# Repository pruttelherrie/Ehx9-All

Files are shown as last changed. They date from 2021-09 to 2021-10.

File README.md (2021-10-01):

## WARNING! 
Do not use the EEPROM store code from before 2021-10-01! It will eat up your flash writes like candy because of the braindead EEPROM.write lib in the stm32duino core. Fixed in callbacks.h and main.cpp, dd 2021-10-01

## Ehx9-All: combining and programming EHX '9' pedals

Electro Harmonix' 9 series of pedals is a range of polyphonic synthesis pedals for guitar. The
effects and sounds that can be obtained are superb, however they have a few shortcomings: 
first of all they are not programmable (i.e. there's only one setting, no way to store 
favourites and recall them quickly) and if you have more than one, they tend to take
up quite a lot of space on a pedalboard, especially if one uses them only sparingly
during a set.

The modifications documented in this repository try to eliminate these shortcomings.

## Programmability

To store and recall settings, the pots and switch are removed. GPIOs from the
microcontroller are connected to the main board to replace the functionality of
the pots and the switch. Since we use a PWM signal for the pots, it is low-pass
filtered by a simple first-order RC network.

Encoders take the place of the pots and the switch, a TFT is added for visual 
feedback of the settings.

## Space saving

All pedals of this serie share the same PCB. The difference is in the firmware of the
DSP. This firmware is stored in an EEPROM. By multiplexing multiple EEPROMS on one
board and resetting the DSP after switching the multiplexer, one can switch between
pedals of the series within one enclosure.

## Implementing the mods

Modding a pedal is not for the faint of heart. It is pretty easy to destroy the pedal
in the process. Also, a number of tools are needed:

* A way to program an Attiny2313. I use a Tuxgraphics AVR programmer, but there's a large number of other options.
* A way to program the STM32 blackpill. I use an ST-Link clone.
* There's SMD (de) soldering involved
* The enclosure is modified

## BOM

The BOMs for the PCBs can be found in their folders:
[controller](./controller-pcb/ibom.html)
[multiplexer](./multiplexer-pcb/ibom.html)

## Firmware

The multiplexer firmware was made with the Arduino IDE.

The controller firmware was made with VSCode + PlatformIO.

## Walkthrough of a mod

TBD: text and images.

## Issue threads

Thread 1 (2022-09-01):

EEPROM

leetut, 2022-09-01:
Hi, how did you copy and write the eeprom?

pruttelherrie, 2022-09-13:
Hi, I did it with flashrom, but I believe you already managed to copy it, seeing the thread on diystompboxes :)

Robertzep, 2023-05-18:
Hi, I would like a little more info on how to copy the eeproms. I'd like to do it from the JTAG connector on the EHX x9 pedal. Also, on the Mel9 there is a larger eeprom (MX25L12833F). How do you deal with it or is the program size the same as the other pedals that use the MX25L6445E? I would like to correspond with you on this project. I've tried to join diystompboxes for awhile and never got an activation. I see that everything is here firmware and PCB's. I have been putting together your data from diystompboxes, imgur.com, and your Youtube channel to make this build a little clearer. Anyway, I have more questions too. You can reply to me on email if you like robertzep[at]neo.rr.com

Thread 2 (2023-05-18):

multiplexer BOM

Robertzep, 2023-05-18:
The BOM for the multiplexer PCB is missing.

pruttelherrie, 2023-05-19:
Added!

Robertzep, 2023-05-19:
Thanks!

Closed 2023-05-19.

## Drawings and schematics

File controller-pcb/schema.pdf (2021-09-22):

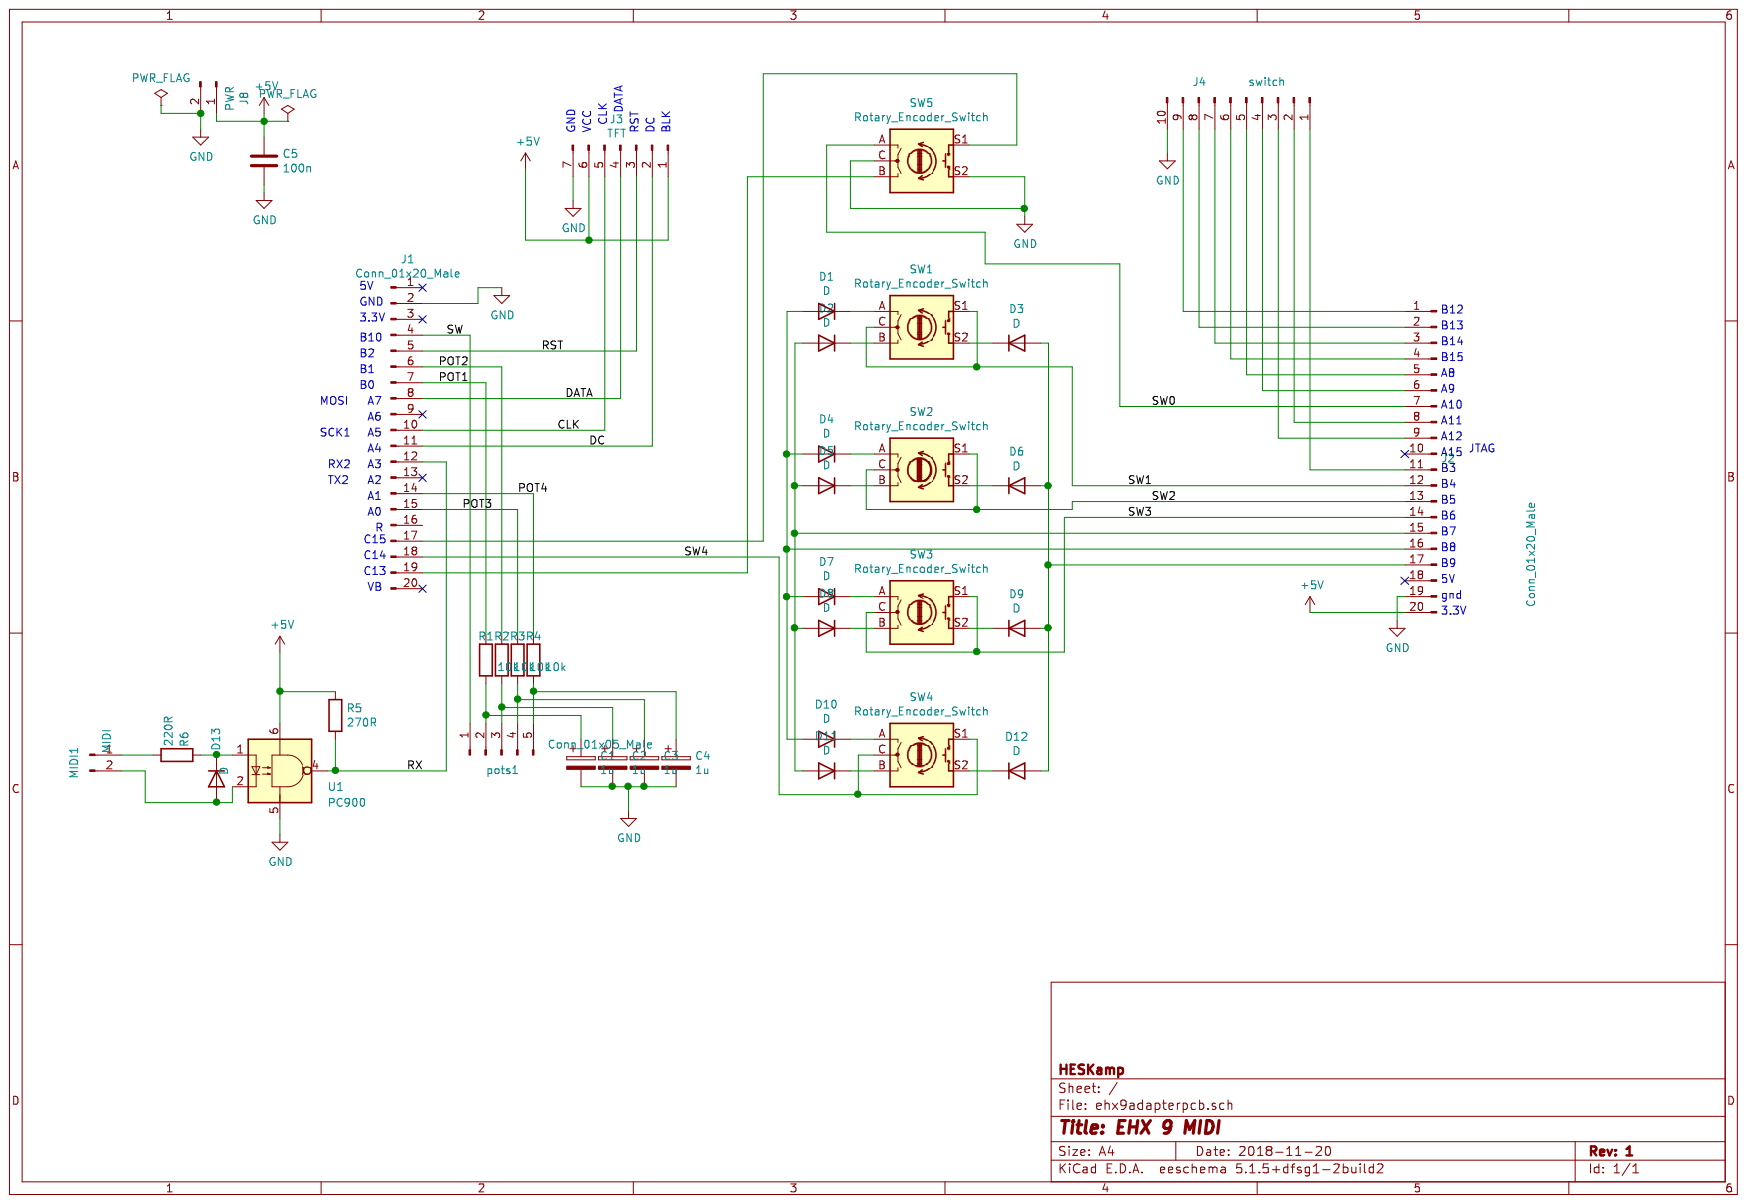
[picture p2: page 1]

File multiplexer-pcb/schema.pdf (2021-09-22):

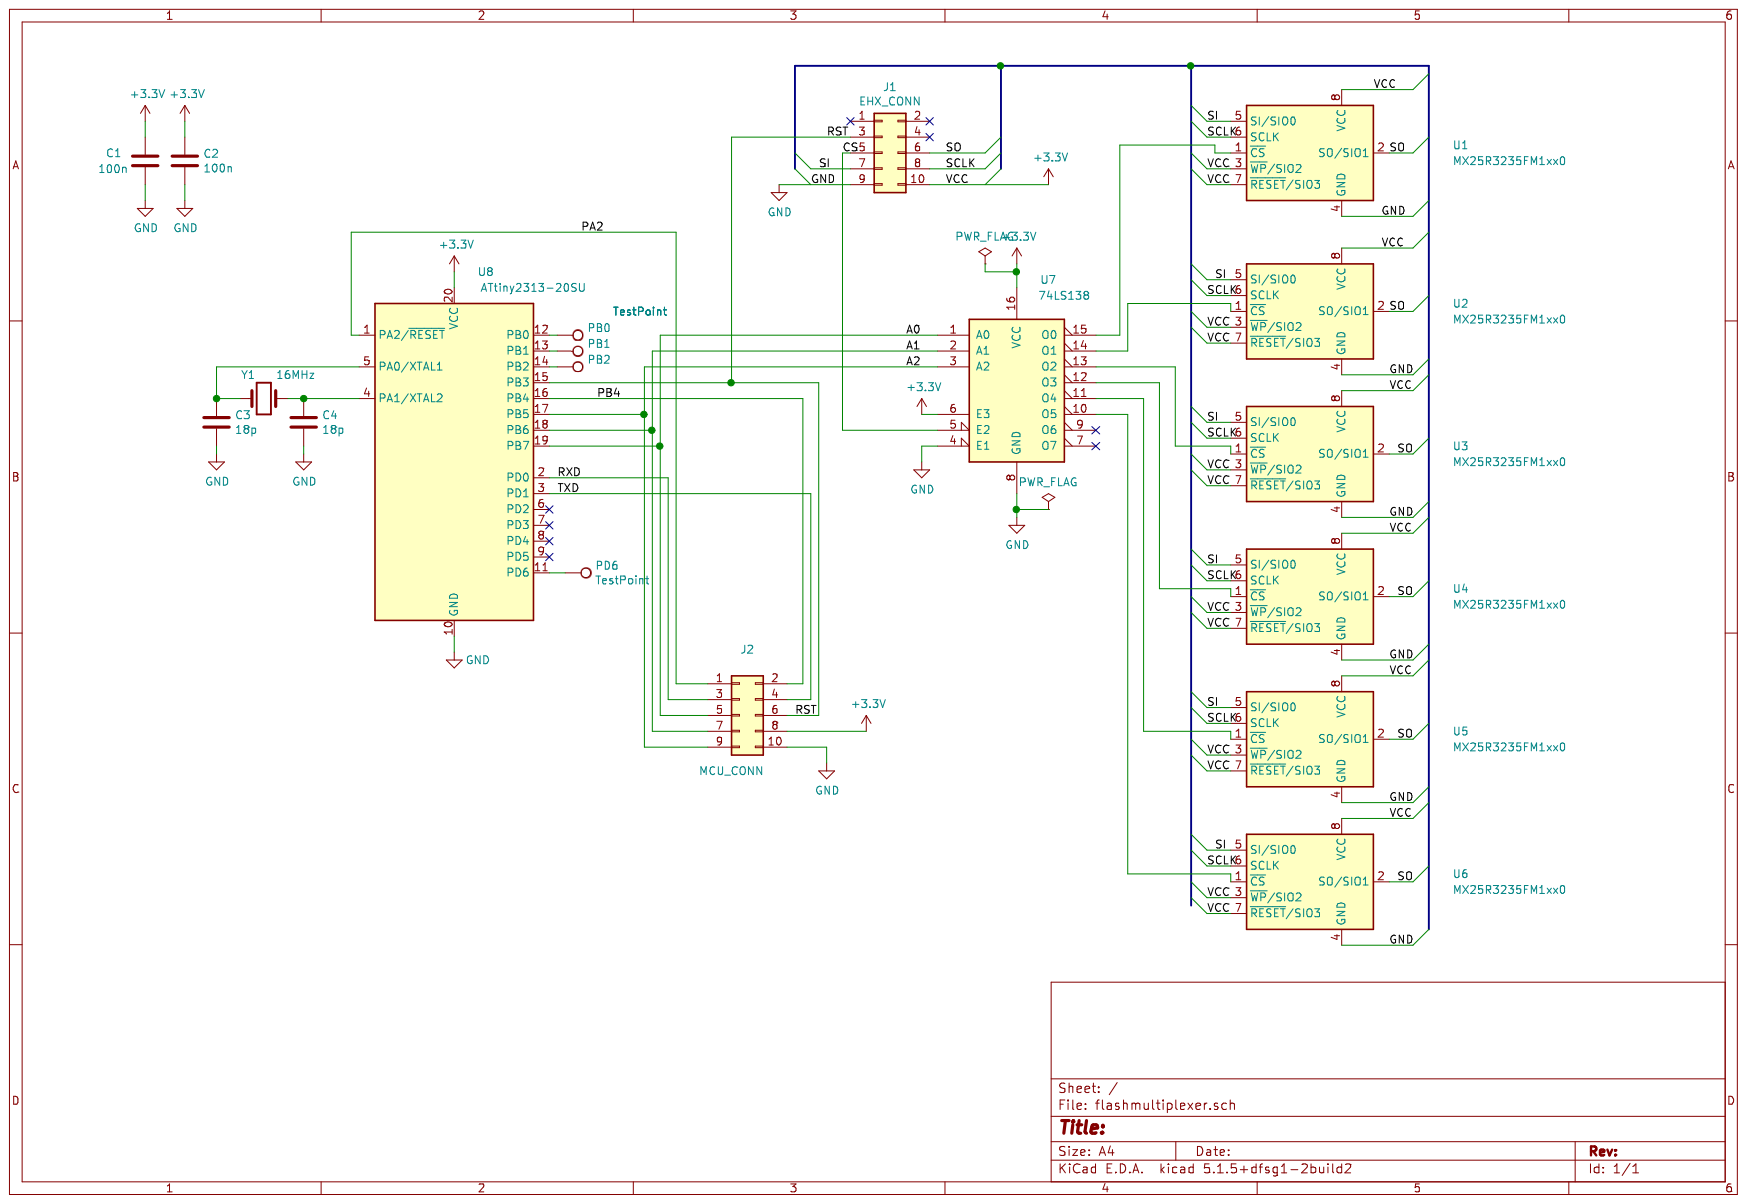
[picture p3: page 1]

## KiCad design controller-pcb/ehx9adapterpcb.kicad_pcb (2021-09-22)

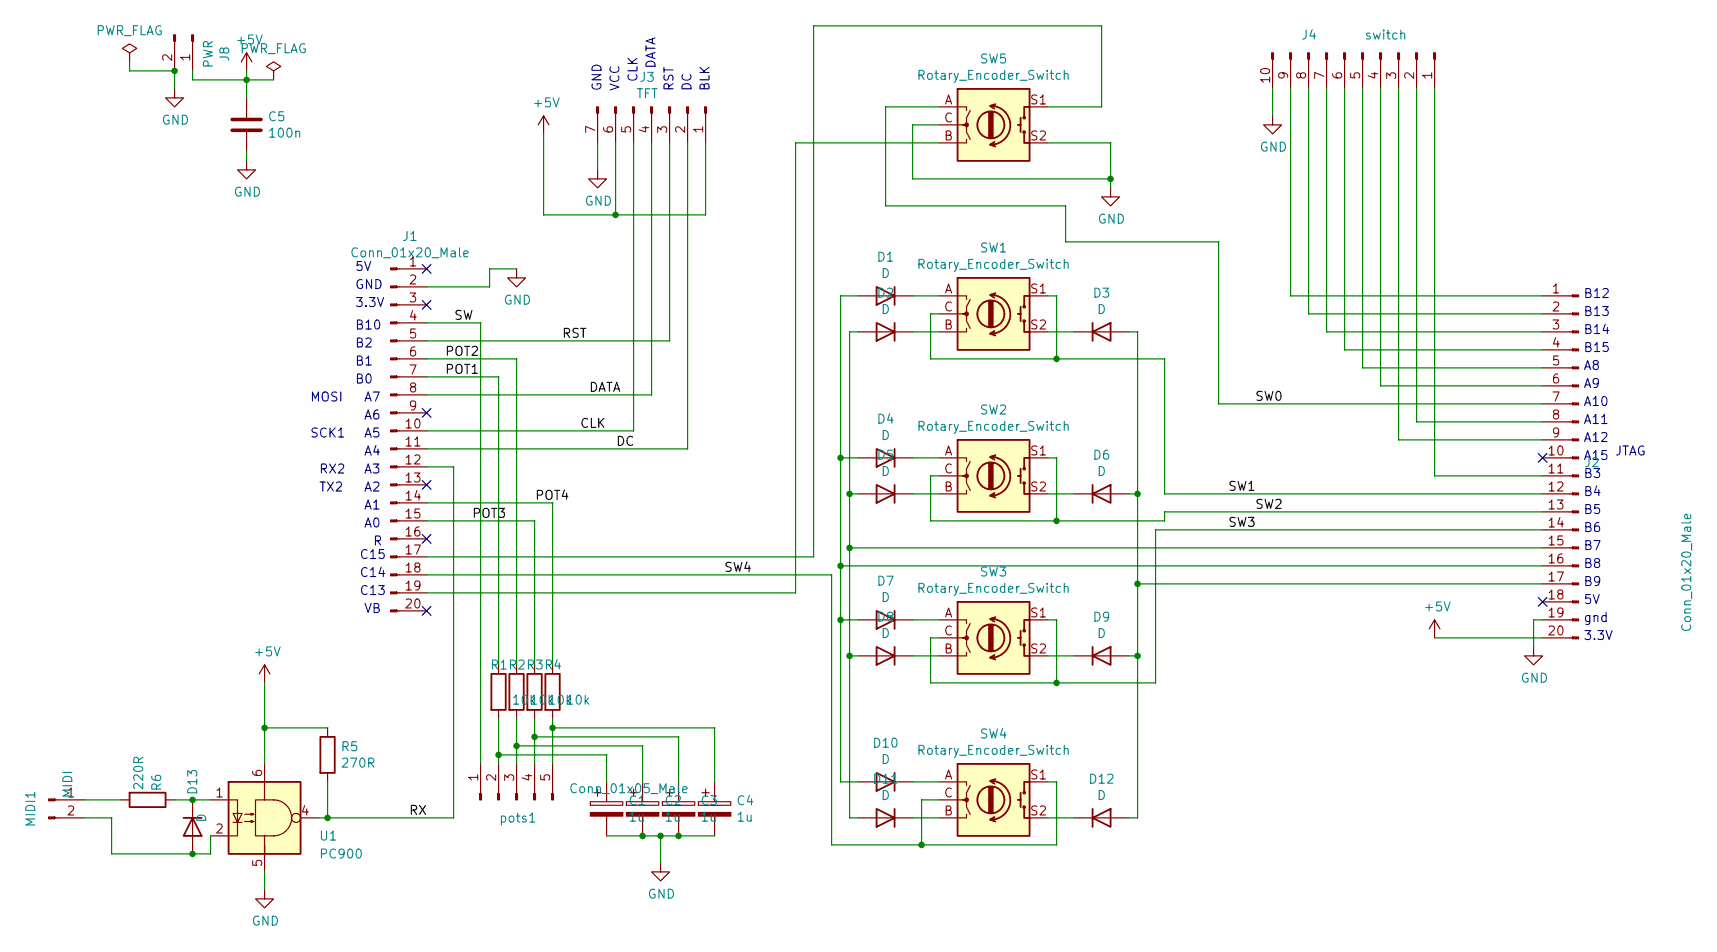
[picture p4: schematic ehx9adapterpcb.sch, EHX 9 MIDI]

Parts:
C1, C2, C3, C4: 1u; CP_Radial_D5.0mm_P2.50mm
C5: 100n; C_Rect_L7.0mm_W2.0mm_P5.00mm
D1, D2, D3, D4, D5, D6, D7, D8, D9, D10, D11, D12: D; D_DO-34_SOD68_P7.62mm_Horizontal
D13: D; D_DO-34_SOD68_P2.54mm_Vertical_KathodeUp
J1, J2: Conn_01x20_Male; PinHeader_1x20_P2.54mm_Vertical
J3: TFT; PinHeader_1x07_P2.54mm_Vertical
J4: switch; PinHeader_1x10_P2.54mm_Vertical
J8: PWR; PinHeader_1x02_P2.54mm_Vertical
MIDI1: MIDI; PinHeader_1x02_P2.54mm_Vertical
R1, R2, R3, R4: 10k; R_Axial_DIN0204_L3.6mm_D1.6mm_P2.54mm_Vertical
R5: 270R; R_Axial_DIN0204_L3.6mm_D1.6mm_P2.54mm_Vertical
R6: 220R; R_Axial_DIN0204_L3.6mm_D1.6mm_P2.54mm_Vertical
SW1, SW2, SW3, SW4, SW5: Rotary_Encoder_Switch; RotaryEncoder_Alps_EC11E-Switch_Vertical_H20mm
U1: PC900; DIP-6_W7.62mm_LongPads
pots1: Conn_01x05_Male; PinHeader_1x05_P2.54mm_Vertical

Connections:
+5V: C5.1, J2.20, J3.1, J3.6, J8.1, R5.1, U1.6
/CLK: J1.10, J3.5
/DATA: J1.8, J3.4
/DC: J1.11, J3.2
/POT1: J1.7, R1.1
/POT2: J1.6, R2.1
/POT3: J1.15, R3.1
/POT4: J1.14, R4.1
/RST: J1.5, J3.3
/RX: J1.12, R5.2, U1.4
/SW: J1.4, pots1.1
/SW0: J2.7, SW5.A
/SW1: J2.12, SW1.C, SW1.S1
/SW2: J2.13, SW2.C, SW2.S1
/SW3: J2.14, SW3.C, SW3.S1
/SW4: J1.18, SW4.C, SW4.S1
GND: C1.2, C2.2, C3.2, C4.2, C5.2, J1.2, J2.19, J3.7, J4.10, J8.2, SW5.C, SW5.S2, U1.5
unnamed: C1.1, R1.2, pots1.2
unnamed: C2.1, R2.2, pots1.3
unnamed: C3.1, R3.2, pots1.4
unnamed: C4.1, R4.2, pots1.5
unnamed: D1.1 (K), SW1.A
unnamed: D1.2 (A), D4.2 (A), D7.2 (A), D10.2 (A), J2.16
unnamed: D2.1 (K), SW1.B
unnamed: D3.1 (K), SW1.S2
unnamed: D4.1 (K), SW2.A
unnamed: D5.1 (K), SW2.B
unnamed: D6.1 (K), SW2.S2
unnamed: D7.1 (K), SW3.A
unnamed: D8.1 (K), SW3.B
unnamed: D9.1 (K), SW3.S2
unnamed: D10.1 (K), SW4.A
unnamed: D11.1 (K), SW4.B
unnamed: D2.2 (A), D5.2 (A), D8.2 (A), D11.2 (A), J2.15
unnamed: D12.1 (K), SW4.S2
unnamed: D3.2 (A), D6.2 (A), D9.2 (A), D12.2 (A), J2.17
unnamed: D13.1 (K), R6.1, U1.1
unnamed: D13.2 (A), MIDI1.2, U1.2
unnamed: J1.17, SW5.S1
unnamed: J1.19, SW5.B
unnamed: J2.1, J4.9
unnamed: J2.2, J4.8
unnamed: J2.3, J4.7
unnamed: J2.4, J4.6
unnamed: J2.5, J4.5
unnamed: J2.6, J4.4
unnamed: J2.8, J4.2
unnamed: J2.9, J4.3
unnamed: J2.11, J4.1
unnamed: MIDI1.1, R6.2

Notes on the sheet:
GND
3.3V
B10
C15
C14
C13
gnd
A15
A12
A11
A10
B15
B14
B13
B12
CLK
SCK1
BLK
RST
DATA
MOSI
VCC
TX2
RX2
JTAG

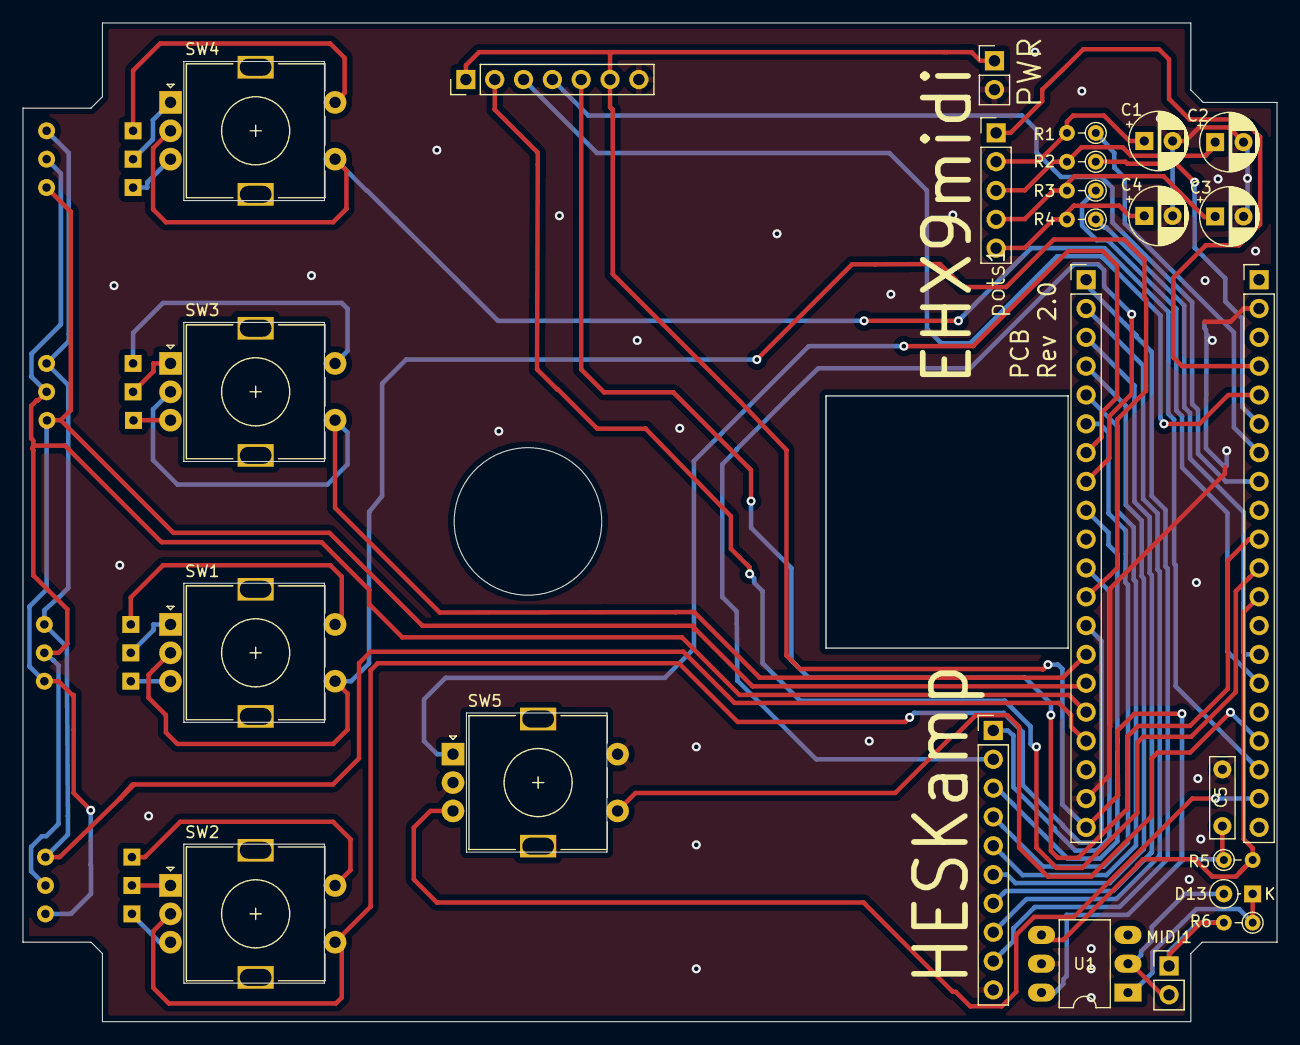
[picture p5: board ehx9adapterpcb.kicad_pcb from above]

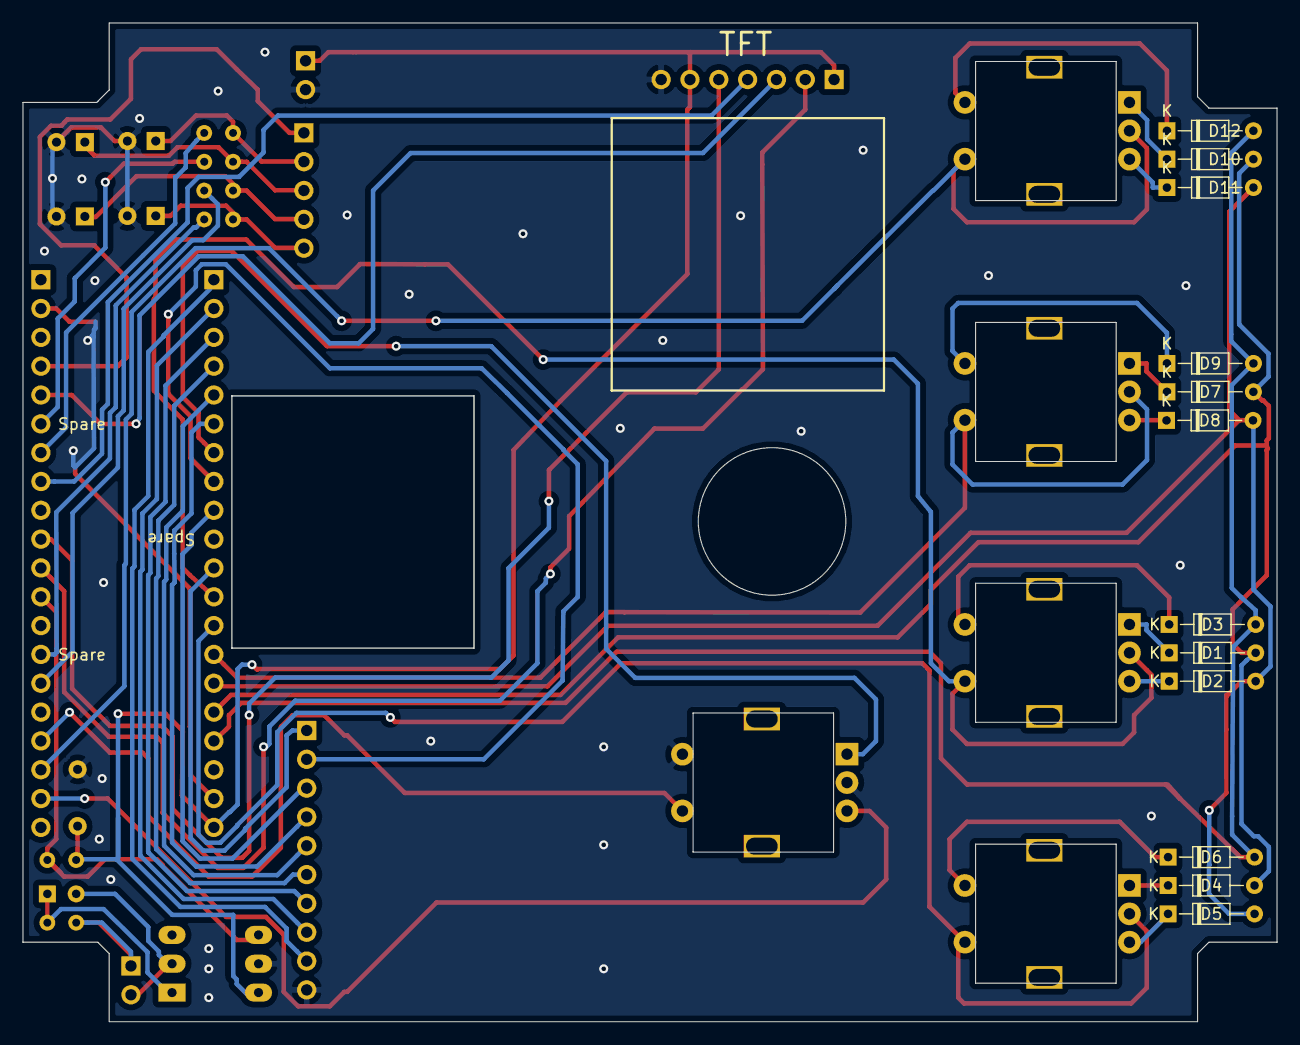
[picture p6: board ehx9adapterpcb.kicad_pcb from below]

Board: 2 copper layers, 110.5 x 88.0 mm, 37 parts (12 on the bottom side), 50 nets.

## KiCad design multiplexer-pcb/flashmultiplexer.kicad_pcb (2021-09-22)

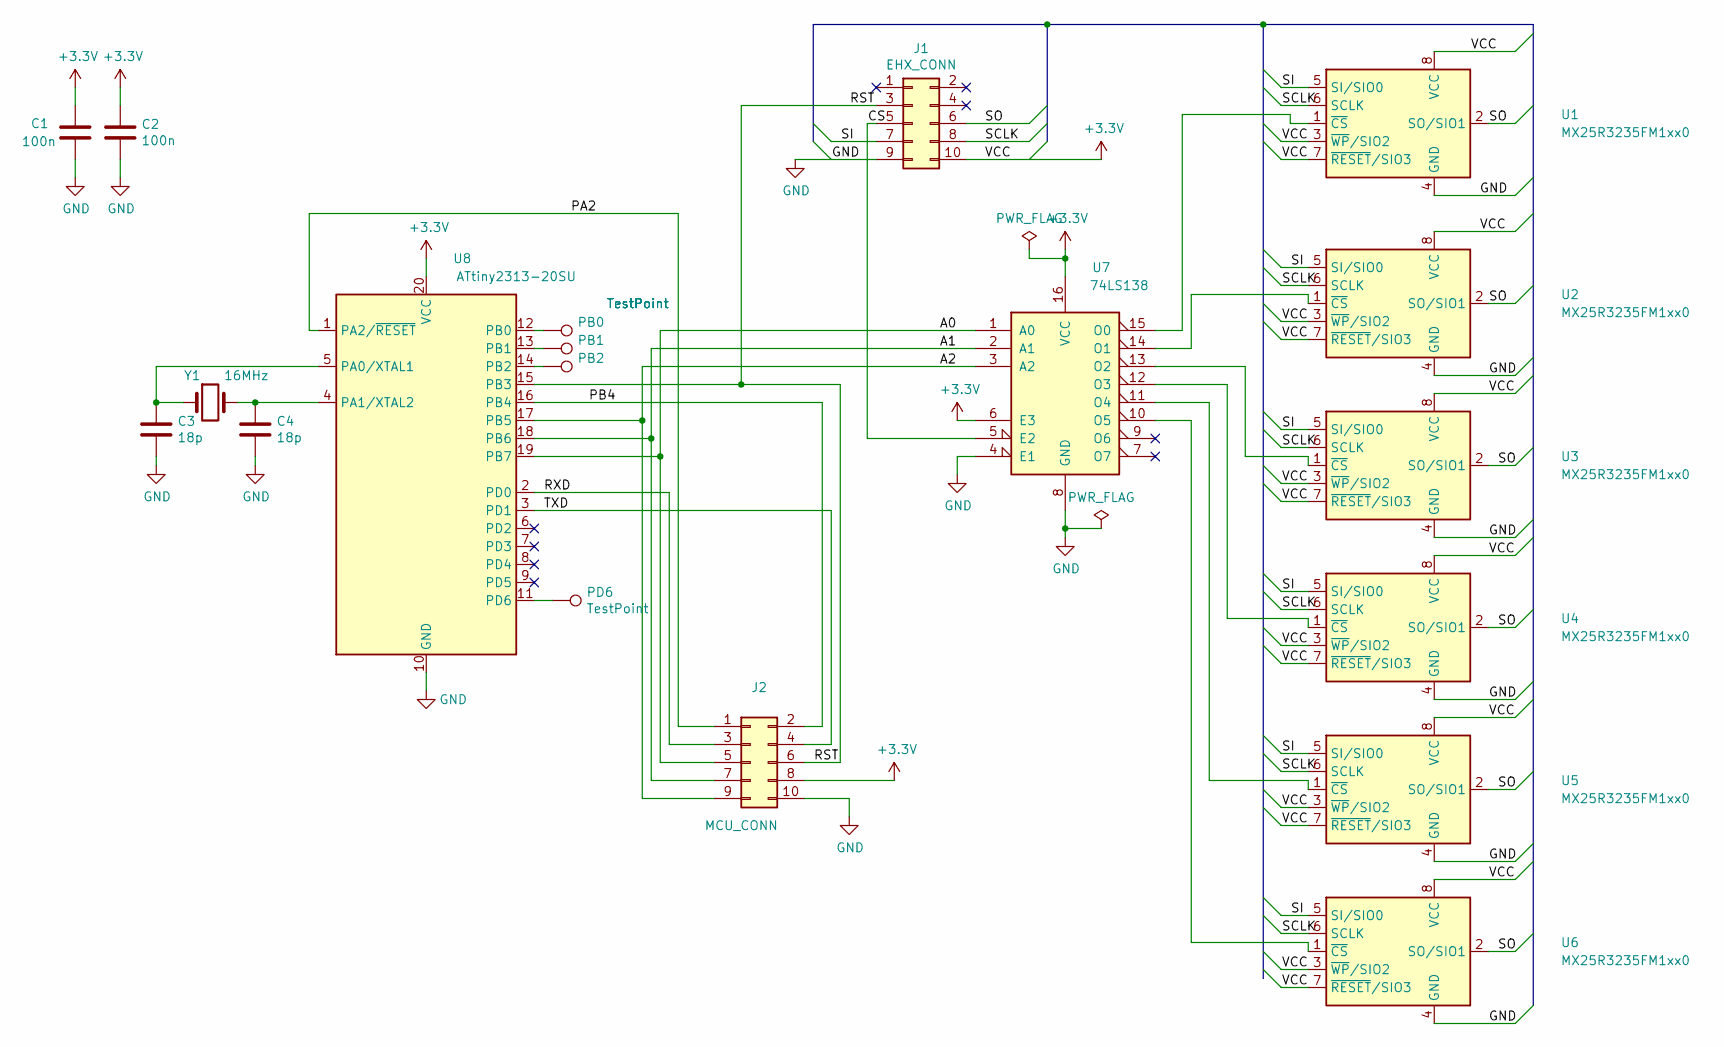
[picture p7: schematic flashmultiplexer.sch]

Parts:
C1, C2: 100n; C_1206_3216Metric
C3, C4: 18p; C_0805_2012Metric
J1: EHX_CONN; PinHeader_2x05_P2.54mm_Vertical
J2: MCU_CONN; PinHeader_2x05_P2.54mm_Horizontal
PB0, PB1, PB2: TestPoint; TestPoint_Pad_D1.5mm
PD6: TestPoint; TestPoint_Pad_D1.5mm
U1: MX25R3235FM1xx0; SOP-8_5.28x5.23mm_P1.27mm
U2, U3, U4, U5, U6: MX25R3235FM1xx0; SOP-8_3.9x4.9mm_P1.27mm
U7: 74LS138; SO-16_5.3x10.2mm_P1.27mm
U8: ATtiny2313-20SU; SOIC-20W_7.5x12.8mm_P1.27mm
Y1: 16MHz; Crystal_SMD_7050-2Pin_7.0x5.0mm_HandSoldering

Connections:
+3V3: C1.1, C2.1, J1.10, J2.8, U1.3 (~WP~/SIO2), U1.7 (~RESET~/SIO3), U1.8 (VCC), U2.3 (~WP~/SIO2), U2.7 (~RESET~/SIO3), U2.8 (VCC), U3.3 (~WP~/SIO2), U3.7 (~RESET~/SIO3), U3.8 (VCC), U4.3 (~WP~/SIO2), U4.7 (~RESET~/SIO3), U4.8 (VCC), U5.3 (~WP~/SIO2), U5.7 (~RESET~/SIO3), U5.8 (VCC), U6.3 (~WP~/SIO2), U6.7 (~RESET~/SIO3), U6.8 (VCC), U7.6 (E3), U7.16 (VCC), U8.20 (VCC)
/A0: J2.5, U7.1 (A0), U8.19 (PB7)
/A1: J2.7, U7.2 (A1), U8.18 (PB6)
/A2: J2.9, U7.3 (A2), U8.17 (PB5)
/CS: J1.5, U7.5 (E2)
/PA2: J2.1, U8.1 (PA2/~RESET)
/PB4: J2.2, U8.16 (PB4)
/RST: J1.3, J2.6, U8.15 (PB3)
/RXD: J2.3, U8.2 (PD0)
/SCLK: J1.8, U1.6 (SCLK), U2.6 (SCLK), U3.6 (SCLK), U4.6 (SCLK), U5.6 (SCLK), U6.6 (SCLK)
/SI: J1.7, U1.5 (SI/SIO0), U2.5 (SI/SIO0), U3.5 (SI/SIO0), U4.5 (SI/SIO0), U5.5 (SI/SIO0), U6.5 (SI/SIO0)
/SO: J1.6, U1.2 (SO/SIO1), U2.2 (SO/SIO1), U3.2 (SO/SIO1), U4.2 (SO/SIO1), U5.2 (SO/SIO1), U6.2 (SO/SIO1)
/TXD: J2.4, U8.3 (PD1)
GND: C1.2, C2.2, C3.2, C4.2, J1.9, J2.10, U1.4 (GND), U2.4 (GND), U3.4 (GND), U4.4 (GND), U5.4 (GND), U6.4 (GND), U7.4 (E1), U7.8 (GND), U8.10 (GND)
unnamed: C3.1, U8.5 (PA0/XTAL1), Y1.1
unnamed: C4.1, U8.4 (PA1/XTAL2), Y1.2
unnamed: PB0.1, U8.12 (PB0)
unnamed: PB1.1, U8.13 (PB1)
unnamed: PB2.1, U8.14 (PB2)
unnamed: PD6.1, U8.11 (PD6)
unnamed: U1.1 (~CS), U7.15 (O0)
unnamed: U2.1 (~CS), U7.14 (O1)
unnamed: U3.1 (~CS), U7.13 (O2)
unnamed: U4.1 (~CS), U7.12 (O3)
unnamed: U5.1 (~CS), U7.11 (O4)
unnamed: U6.1 (~CS), U7.10 (O5)

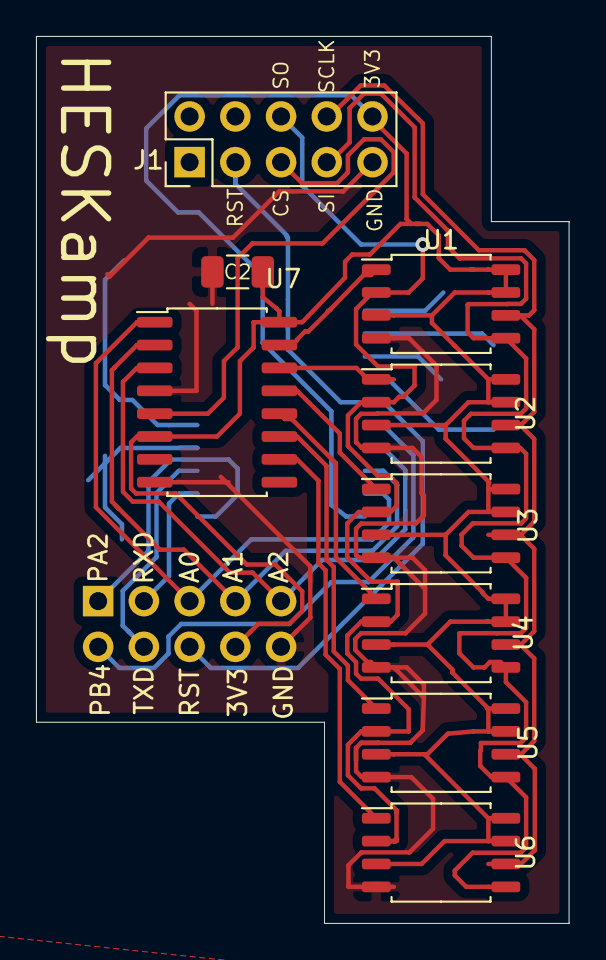
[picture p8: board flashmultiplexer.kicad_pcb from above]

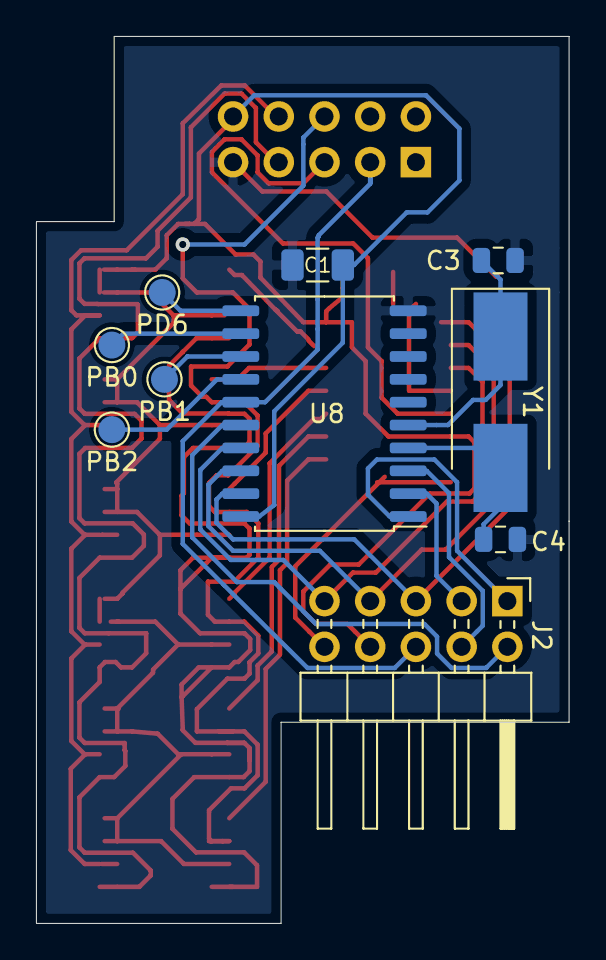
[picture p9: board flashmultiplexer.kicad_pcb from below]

Board: 2 copper layers, 29.6 x 49.3 mm, 19 parts (10 on the bottom side), 26 nets.

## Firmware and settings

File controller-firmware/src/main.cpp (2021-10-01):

#include <Arduino.h>
#include "main.h"
#include "callbacks.h"

// Send command to flash-switcher-PCB
void setPedal(uint8_t pedal, bool reset) {
    if(reset) {
        Serial.write(pedal);
        lastPedal = pedal;
    }
}

void setProgram(uint8_t program) {
    digitalWrite(switchPins[curProgram],HIGH);
    delay(10);
    digitalWrite(switchPins[program],LOW);
    delay(10);
    curProgram = program;
}

void loadPreset(uint8_t preset){
    if(preset >= MAX_PRESETS) {
        return;
    }
    // Load program from memory into menu structure and set effect
    //menuPreset.setCurrentValue(preset);
    menuName.setTextValue( strlen(presetParams[preset].name)  >   0 ? presetParams[preset].name    : "Unnamed");
    menuPedal.setCurrentValue( presetParams[preset].pedal     <   6 ? presetParams[preset].pedal   :   0);
    menuProgram.setCurrentValue( presetParams[preset].program <   9 ? presetParams[preset].program :   0);
    menuDry.setCurrentValue( presetParams[preset].dry         < 101 ? presetParams[preset].dry     :   0);
    menuEffect.setCurrentValue( presetParams[preset].effect   < 101 ? presetParams[preset].effect  : 100);
    menuCtrl1.setCurrentValue( presetParams[preset].ctrl1     < 101 ? presetParams[preset].ctrl1   :  40);
    menuCtrl2.setCurrentValue( presetParams[preset].ctrl2     < 101 ? presetParams[preset].ctrl2   :  60);

    setPedal(menuPedal.getCurrentValue(), lastPedal != menuPedal.getCurrentValue());
    lastPedal = menuPedal.getCurrentValue();
    setProgram(menuProgram.getCurrentValue()); 
}

void printNumber(uint16_t number) {
    char buffer1[16];
    char buffer2[16];
    menuPedal.copyEnumStrToBuffer(buffer1, 16, menuPedal.getCurrentValue());
    strcpy_P(buffer2, programNames[menuPedal.getCurrentValue() * 9 + menuProgram.getCurrentValue()]); 

    spr.fillSprite(0);
    spr.setTextColor(7);
    spr.setTextFont(8);
    spr.setTextDatum(TC_DATUM);
    spr.drawNumber(number + 1, 120, 0); // MIDI PC offset

    spr.setFreeFont(&FreeSans18pt7b);
    spr.setTextColor(14);
    spr.drawString(menuName.getTextValue(), 120, 89);

    spr.setFreeFont(&FreeSans12pt7b);
    uint16_t pedalWidth   = tft.textWidth(buffer1);
    uint16_t programWidth = tft.textWidth(buffer2);
    if(setPedalActive) {
        spr.fillRoundRect(120 - (programWidth - pedalWidth)/2 - 6 - pedalWidth - 2, 135 - 4, pedalWidth + 6, 18 + 8, 2, 11);
        spr.setTextColor(0);
    } else {
        spr.setTextColor(11);
    }
    spr.setTextDatum(TR_DATUM);
    spr.drawString(buffer1, 120 - (programWidth - pedalWidth)/2 - 6, 135); 

    if(setProgramActive) {
        spr.fillRoundRect(120 - (programWidth - pedalWidth)/2 + 6 - 2, 135 - 4, programWidth + 2, 18 + 8, 2, 10);
        spr.setTextColor(0);
    } else {
        spr.setTextColor(10);
    }
    spr.setTextDatum(TL_DATUM);
    spr.drawString(buffer2, 120 - (programWidth - pedalWidth)/2 + 6, 135); 

    spr.setTextDatum(TC_DATUM);

#ifdef UI_KNOBS    
    spr.drawCircle(30 + 0 * 60, 240 - 50, 28, 7);
    spr.drawCircle(30 + 1 * 60, 240 - 50, 28, 7);
    spr.drawCircle(30 + 2 * 60, 240 - 50, 28, 7);
    spr.drawCircle(30 + 3 * 60, 240 - 50, 28, 7);
    spr.setTextDatum(MC_DATUM);
    spr.setTextColor(7);
    spr.drawNumber(menuDry.getCurrentValue(),    30 + 0 * 60, 240 - 50);
    spr.drawNumber(menuEffect.getCurrentValue(), 30 + 1 * 60, 240 - 50);
    spr.drawNumber(menuCtrl1.getCurrentValue(),  30 + 2 * 60, 240 - 50);
    spr.drawNumber(menuCtrl2.getCurrentValue(),  30 + 3 * 60, 240 - 50);
    spr.setFreeFont(&FreeSans9pt7b);
    spr.drawString("Dry",     30 + 0 * 60, 240 - 10);
    spr.drawString("Effect",  30 + 1 * 60, 240 - 10);
    spr.drawString(ctrl1Names[menuPedal.getCurrentValue() * 9 + menuProgram.getCurrentValue()],  30 + 2 * 60, 240 - 10);
    spr.drawString(ctrl2Names[menuPedal.getCurrentValue() * 9 + menuProgram.getCurrentValue()],  30 + 3 * 60, 240 - 10);
#elseif UI_BARS
    spr.drawRect(  0, 150, 115, 20, 9);
    spr.drawRect(125, 150, 115, 20, 9);
    spr.drawRect(  0, 200, 115, 20, 9);
    spr.drawRect(125, 200, 115, 20, 9);
    spr.fillRect(  0, 150, (int32_t)(menuDry.getCurrentValue()    / 100.0 * 115), 20, 9);
    spr.fillRect(125, 150, (int32_t)(menuEffect.getCurrentValue() / 100.0 * 115), 20, 9);
    spr.fillRect(  0, 200, (int32_t)(menuCtrl1.getCurrentValue()  / 100.0 * 115), 20, 9);
    spr.fillRect(125, 200, (int32_t)(menuCtrl2.getCurrentValue()  / 100.0 * 115), 20, 9);

    spr.setTextDatum(MC_DATUM);
    spr.setTextColor(7);
    spr.drawString("Dry",     60, 180);
    spr.drawString("Effect", 180, 180);
    spr.drawString(ctrl1Names[menuPedal.getCurrentValue() * 9 + menuProgram.getCurrentValue()],  60, 240 - 10);
    spr.drawString(ctrl2Names[menuPedal.getCurrentValue() * 9 + menuProgram.getCurrentValue()], 180, 240 - 10);

    spr.setTextColor(14);
    spr.drawNumber(menuDry.getCurrentValue(),     60, 158);
    spr.drawNumber(menuEffect.getCurrentValue(), 180, 158);
    spr.drawNumber(menuCtrl1.getCurrentValue(),   60, 208);
    spr.drawNumber(menuCtrl2.getCurrentValue(),  180, 208);
#else 
    spr.drawRect(  0, 170, 115, 30, 9);
    spr.drawRect(125, 170, 115, 30, 9);
    spr.drawRect(  0, 210, 115, 30, 9);
    spr.drawRect(125, 210, 115, 30, 9);
    spr.fillRect(  0, 170, (int32_t)(menuDry.getCurrentValue()    / 100.0 * 115), 30, 9);
    spr.fillRect(125, 170, (int32_t)(menuEffect.getCurrentValue() / 100.0 * 115), 30, 9);
    spr.fillRect(  0, 210, (int32_t)(menuCtrl1.getCurrentValue()  / 100.0 * 115), 30, 9);
    spr.fillRect(125, 210, (int32_t)(menuCtrl2.getCurrentValue()  / 100.0 * 115), 30, 9);

    spr.setTextDatum(MC_DATUM);
    spr.setTextColor(7);
    spr.drawString("Dry",     58, 183);
    spr.drawString("Effect", 182, 183);
    spr.drawString(ctrl1Names[menuPedal.getCurrentValue() * 9 + menuProgram.getCurrentValue()],  58, 223);
    spr.drawString(ctrl2Names[menuPedal.getCurrentValue() * 9 + menuProgram.getCurrentValue()], 182, 223);
#endif

    spr.pushSprite(0,0);
}

// this is the function called by the renderer every 1/5 second once the display is
// taken over, we pass this function to takeOverDisplay().
void myDisplayFunction(unsigned int encoderValue, RenderPressMode clicked) {
    // we initialise the display on the first call.
    if(counter == 0) {
        switches.changeEncoderPrecision(MAX_PRESETS, menuPreset.getCurrentValue());  
        encoderValue = menuPreset.getCurrentValue();
        doUpdate = true;
        counter++;
    }
    // We are told when the button is pressed in by the boolean parameter.
    // When the button is clicked, we give back to the menu..
    if(clicked) {
        tft.setTextSize(1);
        renderer.giveBackDisplay();
        counter = 0;
    } else { // Program Change! Let op: deze kan ook aangeroepen worden door handleProgramChange()
        if( (menuPreset.getCurrentValue() != encoderValue) || doUpdate) { 
            menuPreset.setCurrentValue(encoderValue);
            switches.getEncoder()->setCurrentReading(encoderValue);
            loadPreset(encoderValue);
            printNumber(encoderValue);
            doUpdate = false;
        } 
        counter++;
    }
}

void setup() {
    eeprom_buffer_fill(); // Copy flash page to eeprom emulation buffer

    uint8_t eeprom_initialised = eeprom_buffered_read_byte(0);
    byte *p = (byte *) &presetParams[0];
    for (uint16_t i = 1; i < 1 + sizeof(presetParams); i++) {
        *p++ = eeprom_buffered_read_byte(i);
    }
    p = (byte *) &settings;
    for (uint16_t i = 1 + sizeof(presetParams); i < 1 + sizeof(presetParams) + sizeof(settings); i++) {
        *p++ = eeprom_buffered_read_byte(i);
    }

    for(uint8_t i=0; i<4; i++) {   // set up knob (pot) outputs
        pinMode(knobPins[i], OUTPUT);
        analogWrite(knobPins[i], 255);
    }

    for(uint8_t i=0; i<9; i++) {   // setup program switch
        pinMode(switchPins[i], OUTPUT);
        digitalWrite(switchPins[i], HIGH);
    }  

    encoders.addEncoder(1, 4, PC14, 2, 100, 0);
    encoders.addEncoder(2, 4, PB6,  2, 200, 0);
    encoders.addEncoder(3, 4, PB4,  1, 300, 399);
    encoders.addEncoder(4, 4, PB5,  1, 400, 499);
    encoders.setDebounce(16);

    Serial.setRx(PA3);
    Serial.setTx(PA2);
    Serial.begin(31250);

    // 4-bit (indexed colormap) sprite for buffered DMA transfers
    spr.setColorDepth(4);
    // We use a Sprite as big as the screen. Here we build the contents then transfer it 
    // in one big DMA push.
    spr.createSprite(240, 240);
    // Create a color map with known colors (16 maximum for 4 bit Sprite)
    uint16_t cmap[16];
    cmap[0]  = TFT_BLACK; // We will keep this as black
    cmap[1]  = TFT_NAVY;
    cmap[2]  = TFT_DARKGREEN;
    cmap[3]  = TFT_DARKCYAN;
    cmap[4]  = TFT_MAROON;
    cmap[5]  = TFT_PURPLE;
    cmap[6]  = TFT_PINK;
    cmap[7]  = TFT_LIGHTGREY;
    cmap[8]  = TFT_YELLOW;
    cmap[9]  = tft.color565(0,63,135); // tcMenu Dark Blue instead of TFT_BLUE
    cmap[10] = TFT_GREEN;
    cmap[11] = TFT_CYAN;
    cmap[12] = TFT_RED;
    cmap[13] = TFT_MAGENTA;
    cmap[14] = TFT_WHITE;  // Keep as white for text
    cmap[15] = TFT_BLUE;   // Keep as blue for sprite border
    // Pass the palette to the Sprite class
    spr.createPalette(cmap);

    //renderer.setResetIntervalTimeSeconds(-1);
    renderer.setResetCallback([] {
        counter = 0;
        renderer.takeOverDisplay(myDisplayFunction);
    });

/* // pas vanaf 2.2 proper
    setTitlePressedCallback([](int id) { 
        withMenuDialogIfAvailable([](MenuBasedDialog* dlg) {
            dlg->setButtons(BTNTYPE_CLOSE, BTNTYPE_NONE);
            dlg->showRam("ARM Example", false);
            char menuVer[10];
            tccore::copyTcMenuVersion(menuVer, sizeof menuVer);
            dlg->copyIntoBuffer(menuVer);
            // FIXME:use TimestampedVersion from build_number_defines.h
        }); 
    }); */

    setupMenu();

    // Start your engines...
    loadPreset(menuPreset.getCurrentValue());
    menuSettingsMIDIChannel.setCurrentValue(settings.midichannel);
    tft.fillScreen(TFT_BLACK);

    // Lift-off!
    renderer.takeOverDisplay(myDisplayFunction);
}

void loop() {
    taskManager.runLoop();

    // SPCP: Simplistische Program Change Parser
    // Deze houdt geen rekening met SysEx messages of Realtime messages. 
    // Keep it civil. No bladed weapons, no surprise buttsex.

    // (1) is er een byte beschikbaar in de buffert?
    while(Serial.available()) {
        // (2) lees byte
        c = Serial.read();
        // (3) als we toe waren aan de data van de PC, neem deze over
        if(next_is_pc) {
            menuPreset.setCurrentValue(c);
            if(counter > 0) {
                switches.getEncoder()->setCurrentReading(c);
                loadPreset(c);
                printNumber(c);
            }
            next_is_pc = false;
        }
        // (4) check of de volgende byte een PC data byte is
        if( (settings.midichannel == 0 || settings.midichannel == (c & 0b1111) ) && ( (c >> 4) == 0b1100) ) {
            next_is_pc = true;
        }
    }

    int code = encoders.readAll();

    // Keep the code explicit to keep it readable...
    if(counter > 0) {
        if(encoders.getMode(1) == 1) { 
            if(!setPedalActive) {
                setPedalActive = true; 
                doUpdate = true; 
            }
        } else {
            if(setPedalActive) {
                setPedalActive = false;
                doUpdate = true;
            }
        } 
        if(encoders.getMode(2) == 1) { 
            if(!setProgramActive) {
                setProgramActive = true; 
                doUpdate = true; 
            }
        } else {
            if(setProgramActive) {
                setProgramActive = false;
                doUpdate = true;
            }
        } 
    }

    if(code != 0) {
        int tmp; 
        switch(code) { 
            case 101: 
                tmp = presetParams[menuPreset.getCurrentValue()].dry - 5;
                if(tmp < 0 ) tmp = 0;   
                presetParams[menuPreset.getCurrentValue()].dry = tmp;
                menuDry.setCurrentValue(tmp);
                break;
            case 100: 
                tmp = presetParams[menuPreset.getCurrentValue()].dry + 5;
                if(tmp > 100 ) tmp = 100;   
                presetParams[menuPreset.getCurrentValue()].dry = tmp;
                menuDry.setCurrentValue(tmp);
                break;
            case 103: 
                tmp = presetParams[menuPreset.getCurrentValue()].pedal - 1;
                if(tmp < 0 ) tmp = 0;   
                presetParams[menuPreset.getCurrentValue()].pedal = tmp;
                menuPedal.setCurrentValue(tmp);
                break;
            case 102: 
                tmp = presetParams[menuPreset.getCurrentValue()].pedal + 1;
                if(tmp > 5 ) tmp = 5;   
                presetParams[menuPreset.getCurrentValue()].pedal = tmp;
                menuPedal.setCurrentValue(tmp);
                break;
            case 201: 
                tmp = presetParams[menuPreset.getCurrentValue()].effect - 5;
                if(tmp < 0 ) tmp = 0;   
                presetParams[menuPreset.getCurrentValue()].effect = tmp;
                menuEffect.setCurrentValue(tmp);
                break;
            case 200: 
                tmp = presetParams[menuPreset.getCurrentValue()].effect + 5;
                if(tmp > 100 ) tmp = 100;   
                presetParams[menuPreset.getCurrentValue()].effect = tmp;
                menuEffect.setCurrentValue(tmp);
                break;
            case 203: 
                tmp = presetParams[menuPreset.getCurrentValue()].program - 1;
                if(tmp < 0 ) tmp = 0;   
                presetParams[menuPreset.getCurrentValue()].program = tmp;
                menuProgram.setCurrentValue(tmp);
                break;
            case 202: 
                tmp = presetParams[menuPreset.getCurrentValue()].program + 1;
                if(tmp > 8 ) tmp = 8;   
                presetParams[menuPreset.getCurrentValue()].program = tmp;
                menuProgram.setCurrentValue(tmp);
                break;
            case 301: 
                tmp = presetParams[menuPreset.getCurrentValue()].ctrl1 - 5;
                if(tmp < 0 ) tmp = 0;   
                presetParams[menuPreset.getCurrentValue()].ctrl1 = tmp;
                menuCtrl1.setCurrentValue(tmp);
                break;
            case 300: 
                tmp = presetParams[menuPreset.getCurrentValue()].ctrl1 + 5;
                if(tmp > 100 ) tmp = 100;   
                presetParams[menuPreset.getCurrentValue()].ctrl1 = tmp;
                menuCtrl1.setCurrentValue(tmp);
                break;
            case 399: 
                tmp = menuPreset.getCurrentValue() - 1;
                if(tmp < 0) tmp = 0;   
                menuPreset.setCurrentValue(tmp);
                if(counter > 0) {
                    switches.getEncoder()->setCurrentReading(tmp);
                    loadPreset(tmp);
                    printNumber(tmp);
                }
                break;
            case 401: 
                tmp = presetParams[menuPreset.getCurrentValue()].ctrl2 - 5;
                if(tmp < 0 ) tmp = 0;   
                presetParams[menuPreset.getCurrentValue()].ctrl2 = tmp;
                menuCtrl2.setCurrentValue(tmp);
                break;
            case 400: 
                tmp = presetParams[menuPreset.getCurrentValue()].ctrl2 + 5;
                if(tmp > 100 ) tmp = 100;   
                presetParams[menuPreset.getCurrentValue()].ctrl2 = tmp;
                menuCtrl2.setCurrentValue(tmp);
                break;  
            case 499: 
                tmp = menuPreset.getCurrentValue() + 1;
                if(tmp > MAX_PRESETS) tmp = MAX_PRESETS;   
                menuPreset.setCurrentValue(tmp);
                if(counter > 0) {
                    switches.getEncoder()->setCurrentReading(tmp);
                    loadPreset(tmp);
                    printNumber(tmp);
                }
                break;     
            default:
                // Unknown or unhandled code, show in topleft corner
                tft.fillRect(0,0,100,20, TFT_BLACK);
                tft.setTextColor(TFT_WHITE);
                tft.setTextDatum(TL_DATUM);
                tft.drawNumber(code, 0, 0);
                delay(500);
                break;
        }
        doUpdate = true;
    }
}

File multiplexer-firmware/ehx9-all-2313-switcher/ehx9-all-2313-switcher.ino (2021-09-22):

/*
 * https://forum.arduino.cc/t/attiny-25-45-85-2313-pin-numbers/81499/4
 * 
 * #define PIN_D0  ( 0)
 * #define PIN_D1  ( 1)
 * #define PIN_A1  ( 2)
 * #define PIN_A0  ( 3)
 * #define PIN_D2  ( 4)
 * #define PIN_D3  ( 5)
 * #define PIN_D4  ( 6)
 * #define PIN_D5  ( 7)
 * #define PIN_D6  ( 8)
 * #define PIN_B0  ( 9)
 * #define PIN_B1  (10)
 * #define PIN_B2  (11)
 * #define PIN_B3  (12)
 * #define PIN_B4  (13)
 * #define PIN_B5  (14)
 * #define PIN_B6  (15)
 * #define PIN_B7  (16)
 * #define PIN_A2  (17) 
 */

#define Addr0       16 // PB7
#define Addr1       15 // PB6
#define Addr2       14 // PB5

#define LED1         9 // PB0
#define LED2        10 // PB1
#define LED3        11 // PB2

#define RST_DSP     12 // PB3
#define SWITCH      13 // PB4

#define NUM_FLASH 4

uint8_t address = 0;

void setPedal(uint8_t address) {
    digitalWrite(Addr0, (address & 1) == 1);
    digitalWrite(Addr1, (address & 2) == 2);
    digitalWrite(Addr2, (address & 4) == 4);

    switch(address) {
        default:
        case 0:
            digitalWrite(LED1, LOW);
            digitalWrite(LED2, HIGH);
            digitalWrite(LED3, HIGH);
            break;
        case 1:
            digitalWrite(LED1, HIGH);
            digitalWrite(LED2, LOW);
            digitalWrite(LED3, HIGH);
            break;
        case 2:
            digitalWrite(LED1, HIGH);
            digitalWrite(LED2, HIGH);
            digitalWrite(LED3, LOW);
            break;
        case 3:
            digitalWrite(LED1, LOW);
            digitalWrite(LED2, HIGH);
            analogWrite(LED3, 5);
            break;
    }
    
    digitalWrite(RST_DSP, LOW);
    pinMode(RST_DSP, OUTPUT); // Pull low
    delay(10);
    pinMode(RST_DSP, INPUT);
    delay(250);
}

void setup() {
    pinMode(Addr0, OUTPUT);
    pinMode(Addr1, OUTPUT);
    pinMode(Addr2, OUTPUT);

    pinMode(LED1, OUTPUT);
    pinMode(LED2, OUTPUT);
    pinMode(LED3, OUTPUT);
    
    pinMode(RST_DSP, INPUT); // Hi-Z
    pinMode(SWITCH, INPUT_PULLUP);

    setPedal(address);
}



void loop() {
    if(digitalRead(SWITCH) == LOW) {
         if(++address >= NUM_FLASH) { 
             address = 0;
         }
         setPedal(address);
    }
}
